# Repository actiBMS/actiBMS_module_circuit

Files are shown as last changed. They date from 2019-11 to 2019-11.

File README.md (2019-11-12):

# diyBMSv5_module_circuit
Version 5 of the diyBMS, this repository contains the pcb project for the cell module

THIS IS A WIP VERSION, SO LAST MINUTE CHANGES COULD BE DONE!

Do it yourself battery management system for Lithium ion battery packs/cells

If you are looking for version 4 of this project take a look here https://github.com/stuartpittaway/diyBMSv4

# How to use, build & support

https://www.youtube.com/stuartpittaway
https://community.openenergymonitor.org/t/diybms-active-balancing/12445/7

# WARNING

This is a DIY product/solution so don’t use this for safety critical systems or in any situation where there could be a risk to life.  

There is no warranty, it may not work as expected or at all.

The use of this project is done so entirely at your own risk.  It may involve electrical voltages which could kill - if in doubt, seek help.

The use of this project may not be compliant with local laws or regulations - if in doubt, seek help.

# License

This work is licensed under a Creative Commons Attribution-NonCommercial-ShareAlike 2.0 UK: England & Wales License.

https://creativecommons.org/licenses/by-nc-sa/2.0/uk/

You are free to:
* Share — copy and redistribute the material in any medium or format
* Adapt — remix, transform, and build upon the material
The licensor cannot revoke these freedoms as long as you follow the license terms.

Under the following terms:
* Attribution — You must give appropriate credit, provide a link to the license, and indicate if changes were made. You may do so in any reasonable manner, but not in any way that suggests the licensor endorses you or your use.
* Non-Commercial — You may not use the material for commercial purposes.
* ShareAlike — If you remix, transform, or build upon the material, you must distribute your contributions under the same license as the original.
* No additional restrictions — You may not apply legal terms or technological measures that legally restrict others from doing anything the license permits.

Notices:
You do not have to comply with the license for elements of the material in the public domain or where your use is permitted by an applicable exception or limitation.

No warranties are given. The license may not give you all of the permissions necessary for your intended use. For example, other rights such as publicity, privacy, or moral rights may limit how you use the material.

# Problem

A DIY Powerwall is the DIY construction of a pack of battery cells to create an energy store which can be used via inverters to power electrical items in the home. Generally cells are salvaged/second hand, and typically use Lithium 18650 cells.

Lithium batteries need to be kept at the same voltage level across a parallel pack. This is done by balancing each cell in the pack to raise or lower its voltage to match the others.

Existing balancing solutions are available in the market place, but at a relatively high cost compared to the cost of the battery bank, so this project is to design a low-cost, simple featured BMS/balancer.

# How it works

Each cell in a battery pack has a monitoring module. Each module have a micro on it that manage all the important task to keep the pack safe. 
This uses AVR ATTINY841 linked together by optoisolated serial ports for communication.

The MCU enable a BYPASS resistor, parallel to the CELL, to dump additional power during charge to keep the pack balanced.
Another solution is to enable the Active Balancing, this feature is based on the ETA3000 chip. It is able to move power between adiacent cells.

A more detailed teory of operation about this inductive converter chip can be read here:
 - https://www.beyondlogic.org/review-li-ion-lipo-lifepo4-lithium-battery-active-equalizer-balancer-energy-transfer-board/
 - https://circuitdigest.com/article/cell-balancing-techniques-and-how-to-use-them

ATTINY841 provides:
* Internal temperature monitoring
* External temperature monitoring
* Autonomous PASSIVE cell voltage balancing
* Autonomous ACTIVE cell voltage balancing

# How as v5 improved over v4?

* Greater discharge current
* Better thermal design for the passive balancing tecnique
* Inductive Active Balancing - Low heat production, less energy loss from your PV

# Design Goals

* Build upon my existing skill set and knowledge. 
* Building something that others can contribute to using regular standard libraries and off the shelf components.
* Build something that is inheriently safe and easy to use
* Document it to inspire other people

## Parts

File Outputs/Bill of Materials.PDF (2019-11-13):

Comment | Description | Designator | Quantity | Supplier | SuppliersPartNum ber | Manufacturer | PartNumber
100nF | Chip capacitors | C1 | 1 | LC | C49678 | YAGEO | CC0805KRX7R9BB 104
2.2uF | Chip capacitors | C2 | 1 | LC | C49217 | Guangdong Fenghua Advanced Tech | 0805F225M500NT
10uF | Chip capacitors | C3, C6, C7 | 3 | LC | C15850 | Samsung Electro-Mechanics | CL21A106KAYNN NE
1nF | Chip capacitors | C4 | 1 | LC | C46653 | Samsung Electro-Mechanics | CL21B102KBCNN NC
10nF | Chip capacitors | C5 | 1 | LC | C1710 | Samsung Electro-Mechanics | CL21B103KBANN NC
LM4040B-2.0 | Precision Shunt Voltage Reference | D1 | 1
0805 Blue | LED | D2 | 1 | LC | C2293
0805 Red | LED | D3 | 1 | LC | C84256 | Foshan NationStar Optoelectronics | FC-2012HRK-620D
JST PH 4POS 2.00mm | JST-PH Conn | J1 | 1 | LC | C157926 | JST Sales America | S4B-PH-K-S(LF)(SN)
JST PH 2POS 2.00mm | JST-PH Conn | J2, J5 | 2 | LC | C173752 | JST Sales America | S2B-PH-K-S(LF)(SN)
JST PH 3POS 2.00mm | JST-PH Conn | J3 | 1 | LC | C157929 | JST Sales America | S3B-PH-K-S(LF)(SN)
AVR-ISP-6 | | J6 | 1 | LC | C65114 | Boom Precision Elec | C65114
SM3521-1R0MT | Power Inductor | L1 | 1 | LC | C55366 | Shun Xiang Nuo Elec | SM3521-1R0MT
WS2812B-Mini | RGB Addressable LED | LED1 | 1 | LC | C114583 | Worldsemi | WS2812B-Mini
2Ω ±1% | Chip resistor | PR1, PR2, PR3, PR4, PR5, PR6, PR7, PR8, PR9, PR10, PR11, PR12 | 12 | LC | C49298 | Uniroyal Elec | 25121WF200KT4 E
IRLML6244TRPBF | MOSFET-N | Q1, Q2 | 2 | LC | C143946 | Infineon Technologies | IRLML6244TRPBF
10KΩ ±1% | Chip resistor | R1 | 1 | LC | C17414 | Uniroyal Elec | 0805W8F1002T5E
1KΩ ±1% | Chip resistor | R2 | 1 | LC | C17513 | Uniroyal Elec | 0805W8F1001T5E
402KΩ ±1% | Chip resistor | R3 | 1 | LC | C17680 | Uniroyal Elec | 0805W8F4023T5E
510KΩ ±1% | Chip resistor | R4 | 1 | LC | C17733 | Uniroyal Elec | 0805W8F4023T5E
NCP21WB473J03RA | NTC Resistor 47K 5% | R5 | 1 | LC | C113141 | Murata Electronics | NCP21WB473J03 RA
47KΩ ±1% | Chip resistor | R6, R7, R9, R12, R16 | 5 | LC | C17713 | Uniroyal Elec | 0805W8F4702T5E
510Ω ±1% | Chip resistor | R8, R11 | 2 | LC | C17734 | Uniroyal Elec | 0805W8F5100T5E
2.2KΩ ±1% | Chip resistor | R10, R15 | 2 | LC | C17520 | Uniroyal Elec | 0805W8F2201T5E
51KΩ ±1% | Chip resistor | R17 | 1 | LC | C17737 | Uniroyal Elec | 0805W8F5102T5E
ATTINY841-SSU | AtTiny AVR | U1 | 1 | LC | C219103 | Microchip Tech | ATTINY841-SSU
HMHA2801 | Optocoupler | U2 | 1 | LC | C258257 | ON Semicon | HMHA2801AR2
ETA3000D2L | Inductive Cell Balancer IC | U3 | 1 | | | ETA Solutions | ETA3000D2L

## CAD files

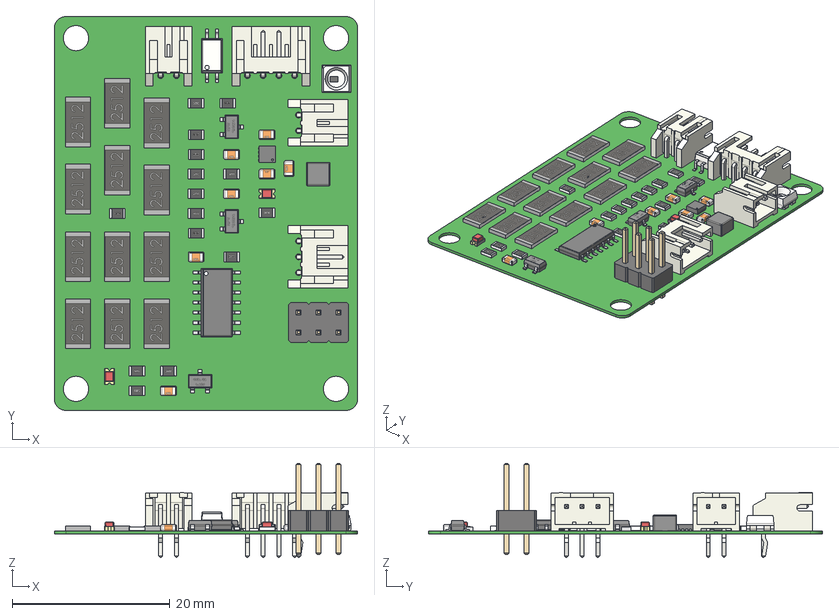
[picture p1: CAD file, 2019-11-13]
Outputs/board.step
38.5 x 50.0 x 11.9 mm
PinHeader_2x03_P2.54mm_Vertical
JST_PH_S2B-PH-K_1x02_P2.00mm_Horizontal x 2
JST_PH_S3B-PH-K_1x03_P2.00mm_Horizontal
JST_PH_S4B-PH-K_1x04_P2.00mm_Horizontal
Open_CASCADE_STEP_translator_6.8_19.1
Open_CASCADE_STEP_translator_6.8_19.2.1
Thermal_Shape
Open_CASCADE_STEP_translator_6.8_19.4.1 x 8
WS2812B_Mini
L_Wuerth_MAPI-3020
Open_CASCADE_STEP_translator_6.8_24.2
Leader x 18
Open_CASCADE_STEP_translator_6.8_8.1
Open_CASCADE_STEP_translator_6.8_8.2.1
User_Library-R_0805 x 15
SOT-23 x 3
User_Library-res2512_body x 12
User_Library-led_0805 x 2
User_Library-0805_SMD_Capacitor x 7

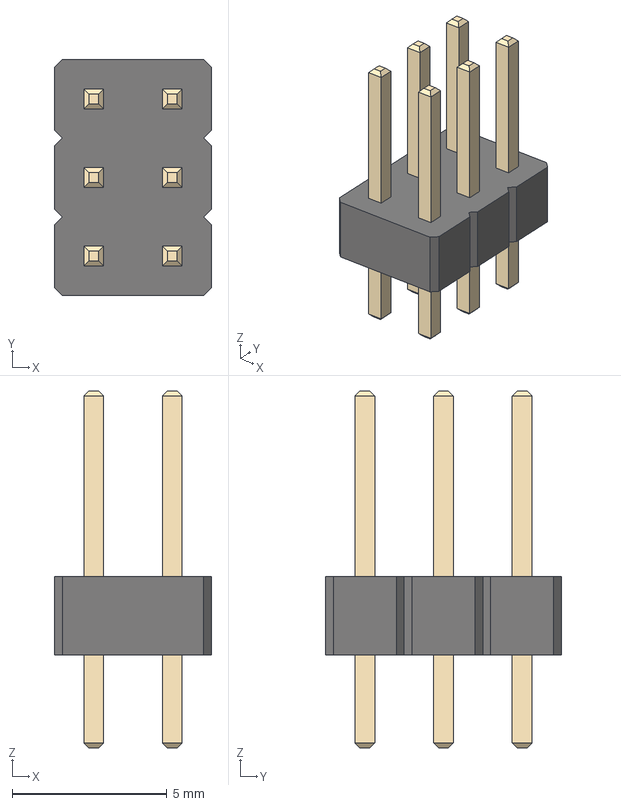
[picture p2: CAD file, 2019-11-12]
PinHeader_2x03_P2.54mm_Vertical.step
5.08 x 7.62 x 11.5 mm

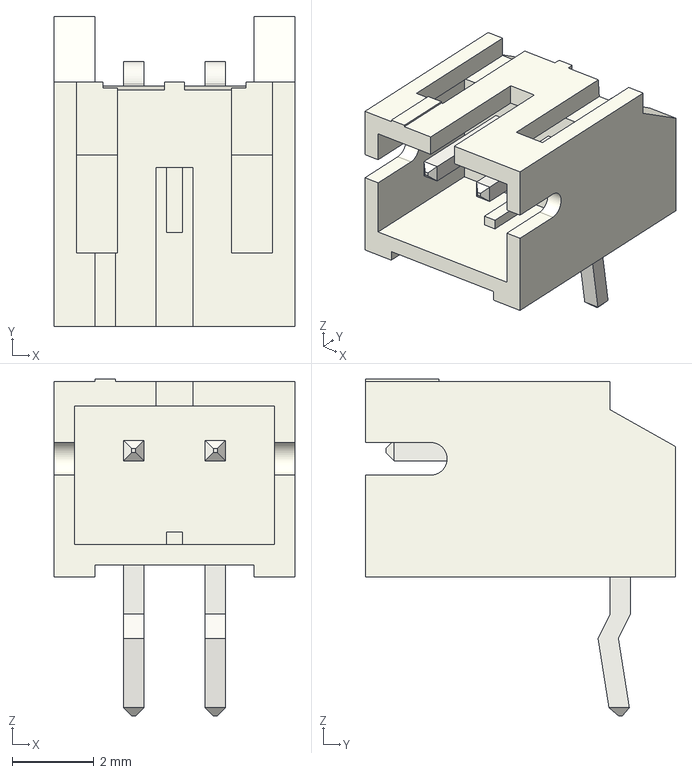
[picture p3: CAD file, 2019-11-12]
JST_PH_S2B-PH-K_1x02_P2.00mm_Horizontal.step
5.90 x 7.60 x 8.25 mm

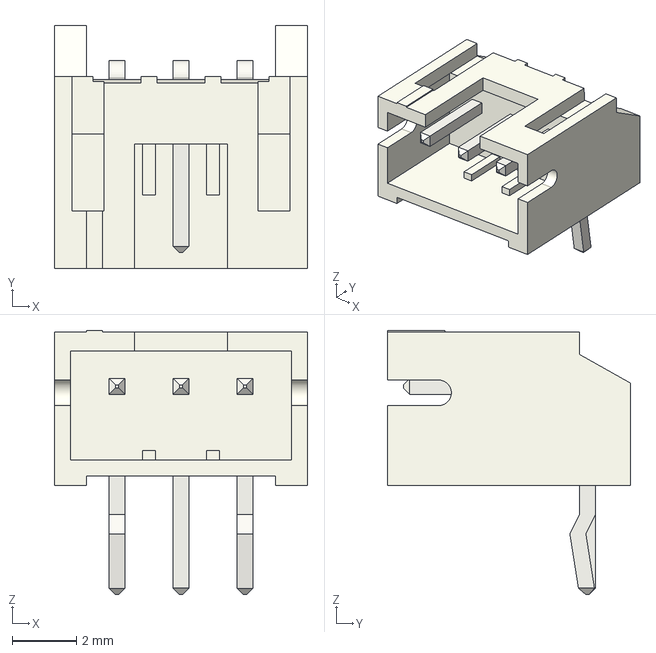
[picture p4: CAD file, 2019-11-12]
JST_PH_S3B-PH-K_1x03_P2.00mm_Horizontal.step
7.90 x 7.60 x 8.25 mm

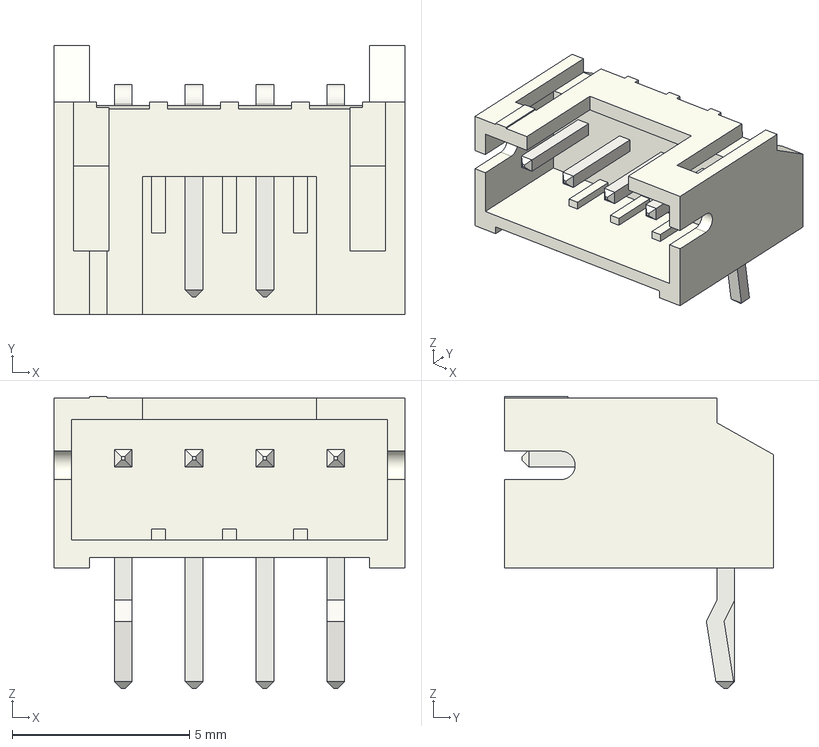
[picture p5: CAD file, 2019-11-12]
JST_PH_S4B-PH-K_1x04_P2.00mm_Horizontal.step
9.90 x 7.60 x 8.25 mm

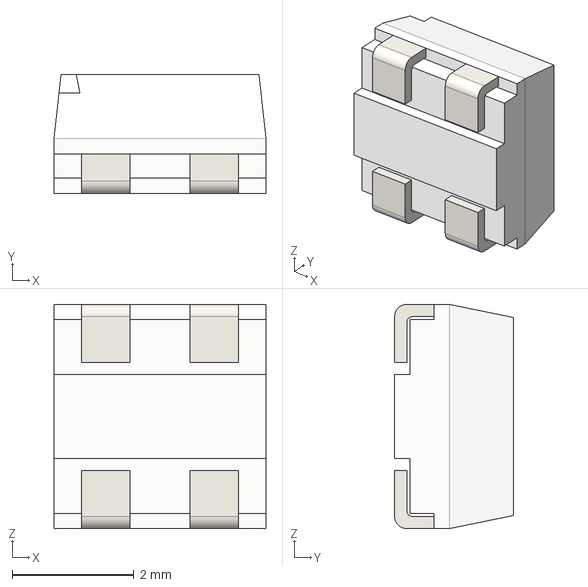
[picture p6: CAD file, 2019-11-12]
WS2812B Mini.step
3.48 x 1.95 x 3.68 mm

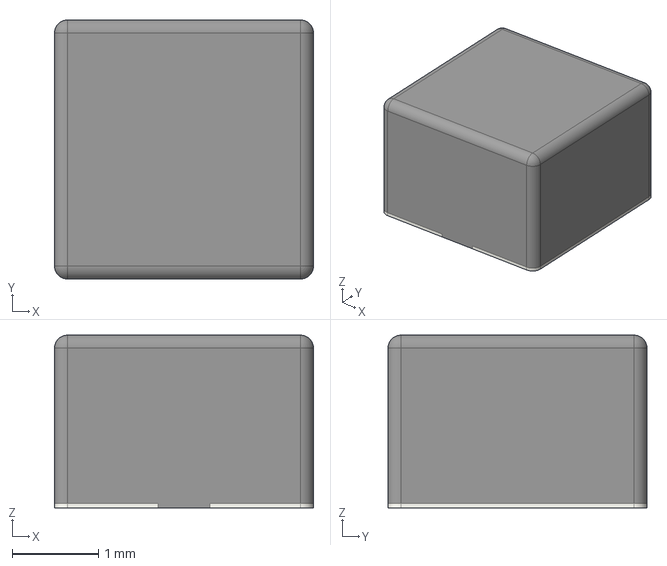
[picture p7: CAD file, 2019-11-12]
L_Wuerth_MAPI-3020.step
3.00 x 3.00 x 2.00 mm

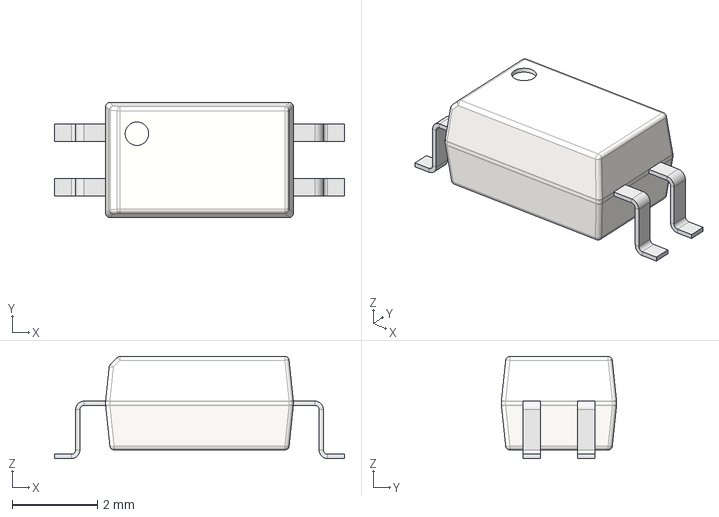
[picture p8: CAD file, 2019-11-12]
HMHA2801 v2.step
6.79 x 2.70 x 2.39 mm
Open_CASCADE_STEP_translator_6.8_24.2
Leader x 4

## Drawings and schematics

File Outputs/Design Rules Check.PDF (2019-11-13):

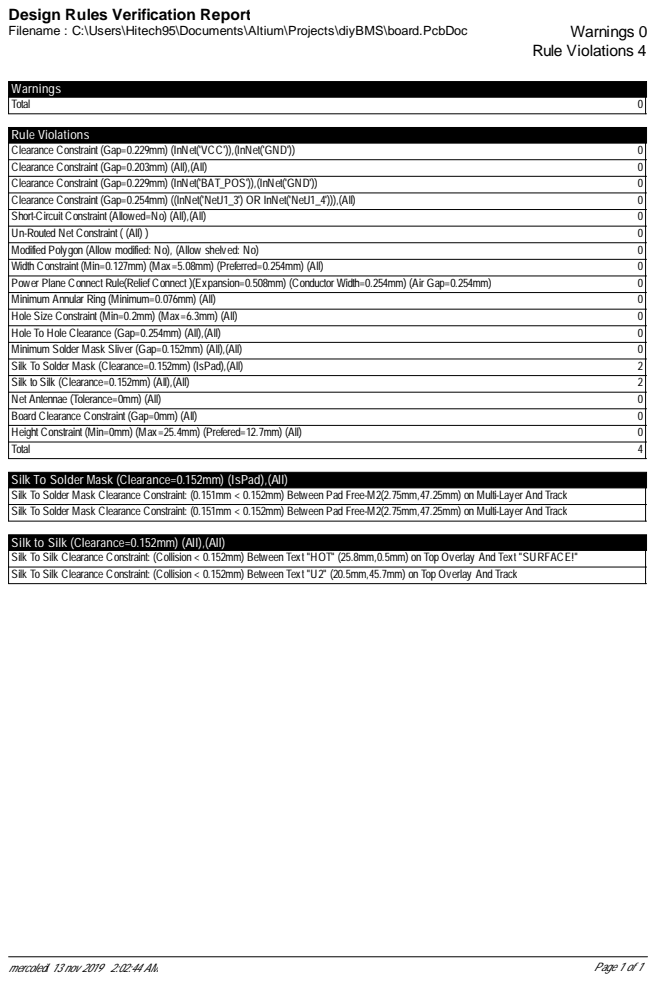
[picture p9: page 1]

Design Rules Verification Report

Silk To Solder Mask (Clearance=0.152mm) (IsPad),(All)
Silk To Solder Mask Clearance Constraint: (0.151mm < 0.152mm) Between Pad Free-M2(2.75mm,47.25mm) on Multi-Layer And Track

Silk to Silk (Clearance=0.152mm) (All),(All)
Silk To Silk Clearance Constraint: (Collision < 0.152mm) Between Text "HOT" (25.8mm,0.5mm) on Top Overlay And Text "SURFACE!"
Silk To Silk Clearance Constraint: (Collision < 0.152mm) Between Text "U2" (20.5mm,45.7mm) on Top Overlay And Track

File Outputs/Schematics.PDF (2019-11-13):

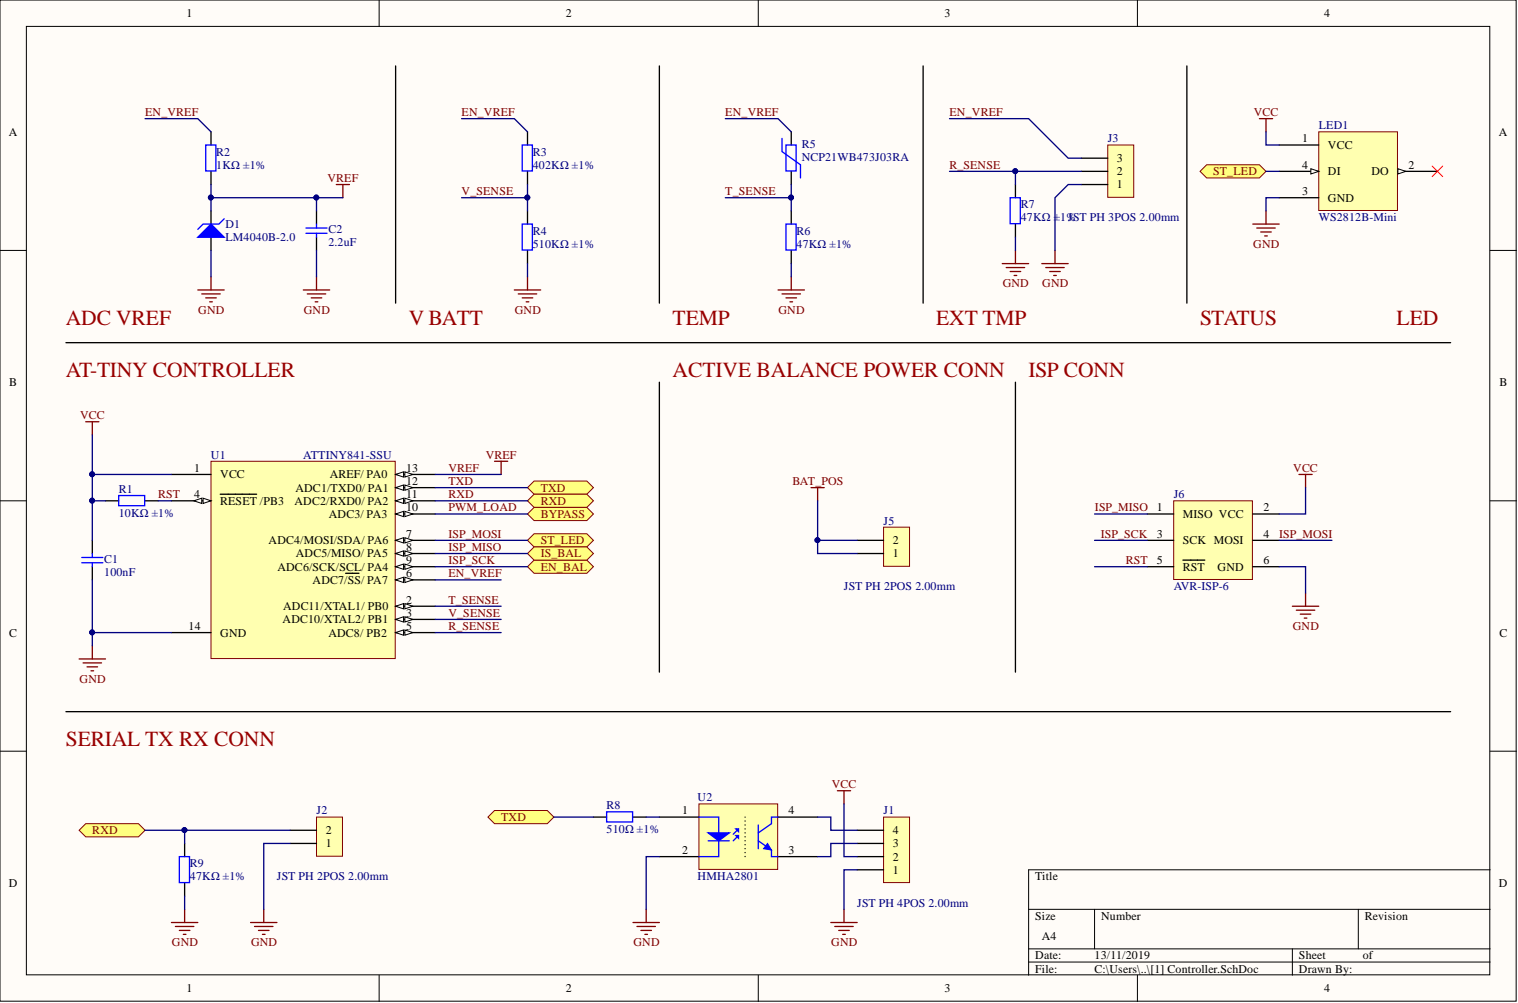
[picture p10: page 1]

ACTIVE BALANCE POWER CONN

SERIAL TX RX CONN

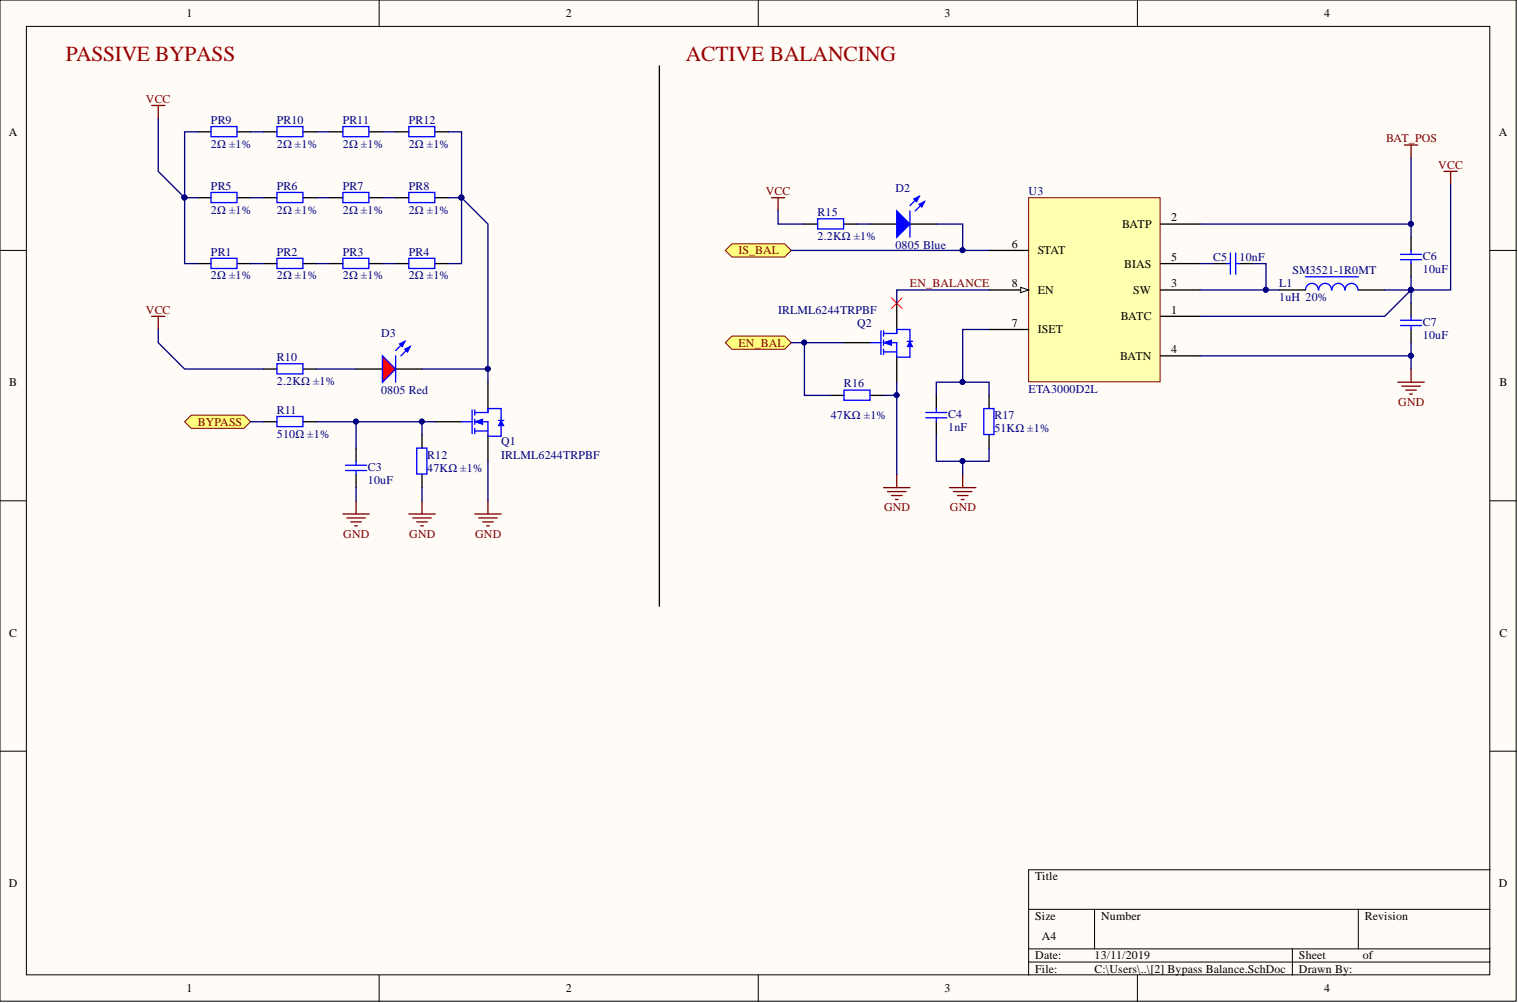
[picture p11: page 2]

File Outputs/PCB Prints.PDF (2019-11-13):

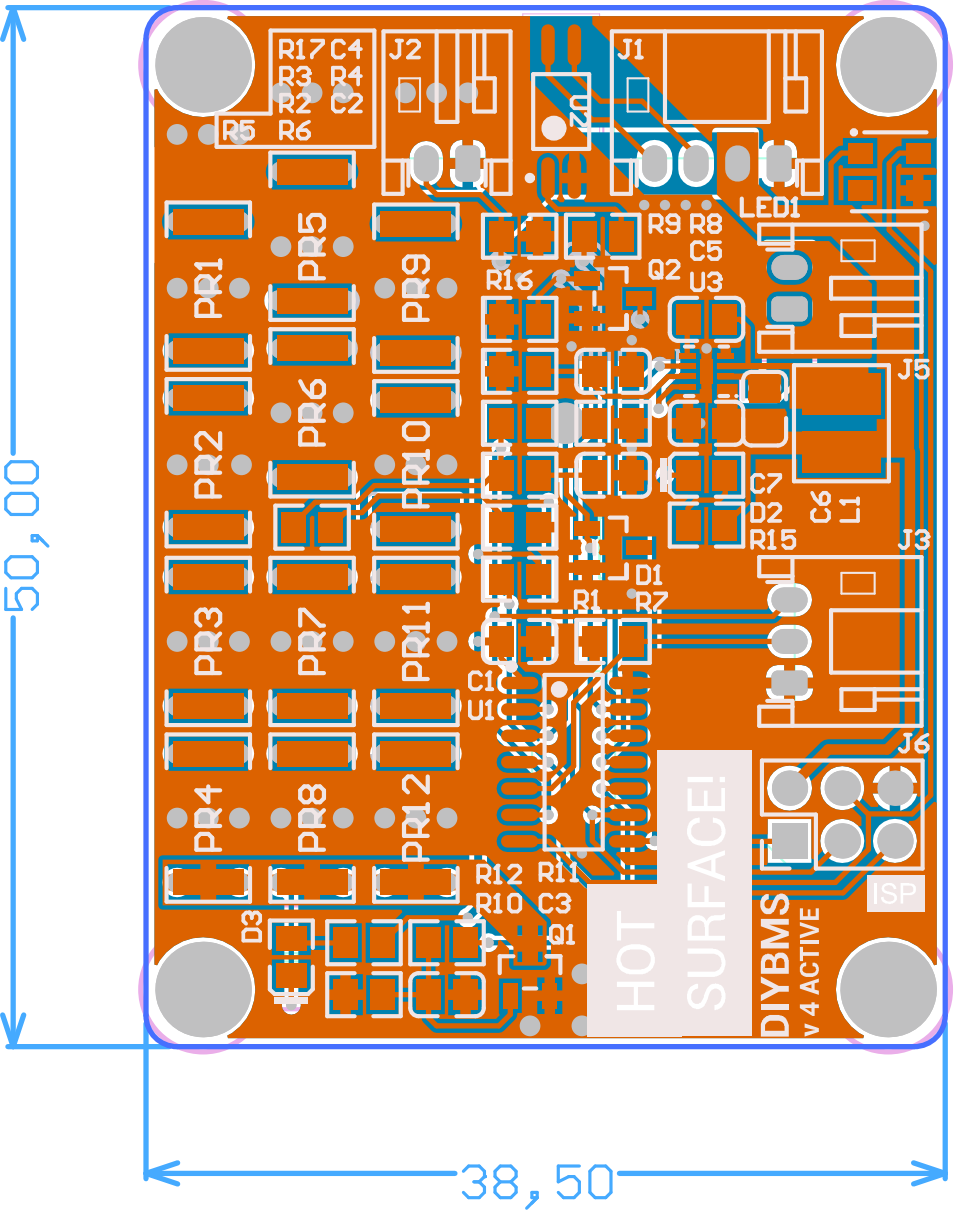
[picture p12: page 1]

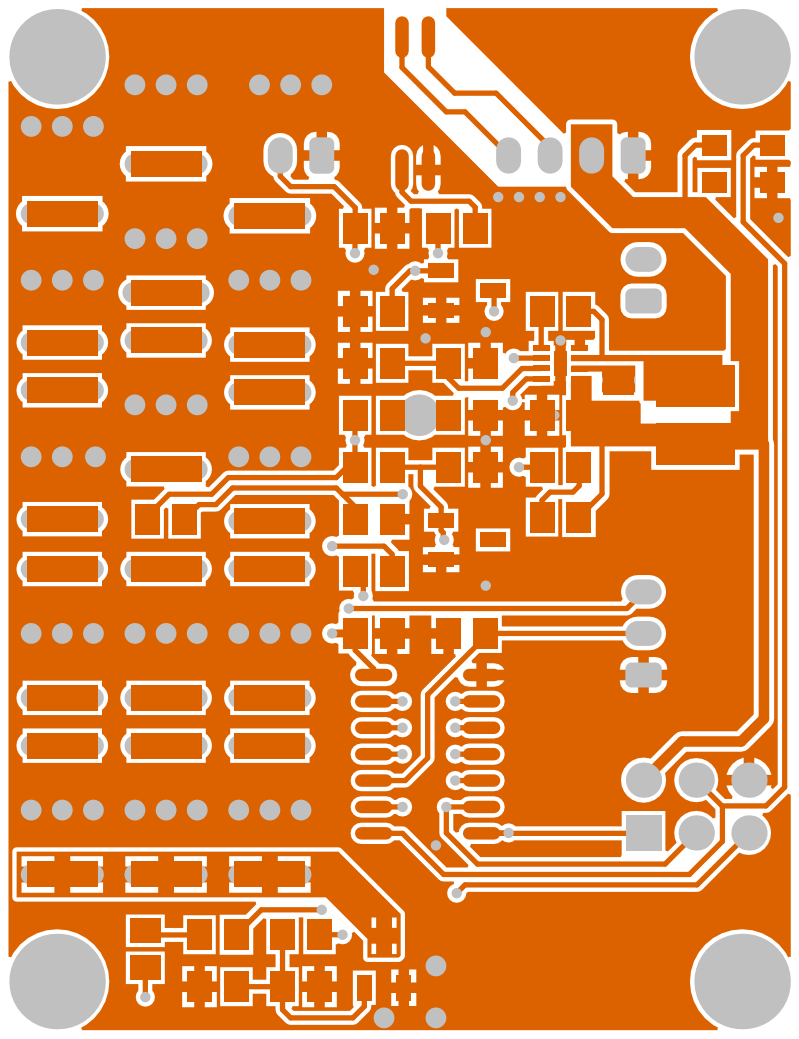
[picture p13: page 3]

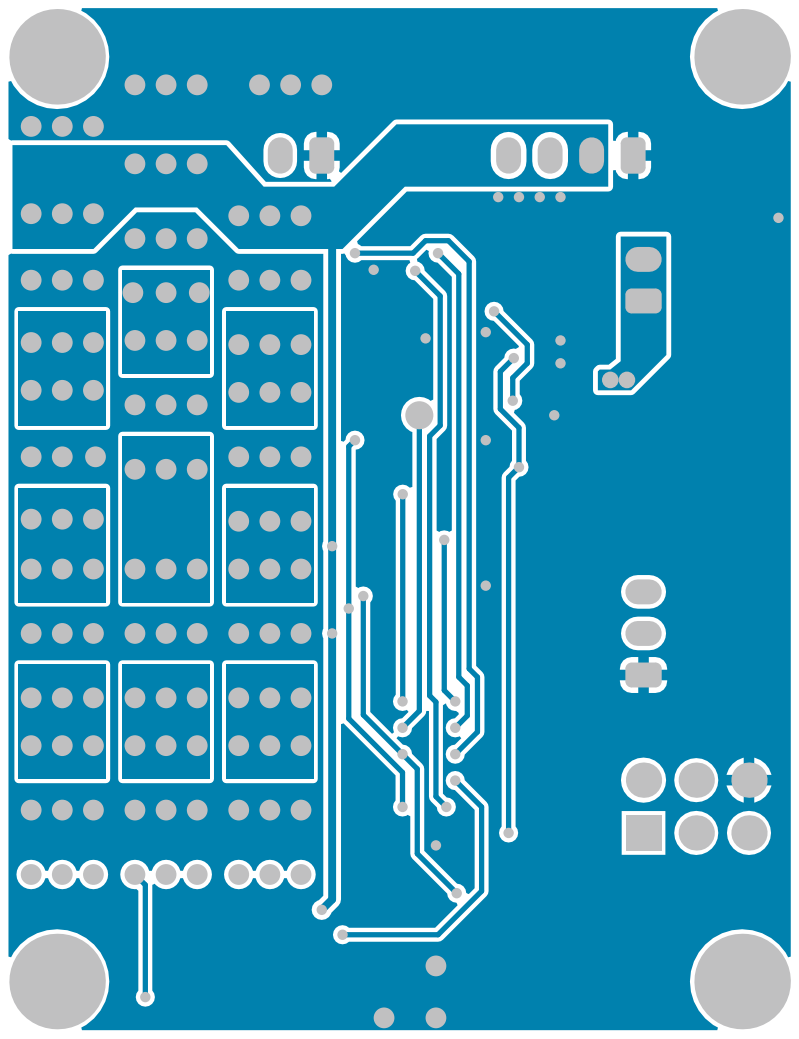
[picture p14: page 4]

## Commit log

2019-11-12 [3D] Upload the 3D Models used by the footprints
    [HMHA2801 v2.step, JST_PH_S2B-PH-K_1x02_P2.00mm_Horizontal.step, JST_PH_S3B-PH-K_1x03_P2.00mm_Horizontal.step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]
2019-11-12 Commit of SCH and PCB
    [BMS_PcbLib.PcbLib, BMS_SchLib.SchLib, [1] Controller.SchDoc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]
2019-11-12 Add Oputput files
    Some of thoose are still not usable, the export process has not been completly configured!
    [Bill of Materials-diyBMS.xlsx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]
2019-11-13 Fixed a libraries, updated project files
    [BMS_PcbLib.PcbLib, [1] Controller.SchDoc, [2] Bypass Balance.SchDoc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]
2019-11-13 Update Outputs
    [Bill of Materials-diyBMS.xlsx, Pick Place for board.csv, board.step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]
2019-11-15 Move from ATtiny to ATmega to have more SRAM, Flash and its cheaper! ATmega168p can also be assembled by SMT process at JLCPCB
    [BMS_PcbLib.PcbLib, BMS_SchLib.SchLib, [1] Controller.SchDoc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]

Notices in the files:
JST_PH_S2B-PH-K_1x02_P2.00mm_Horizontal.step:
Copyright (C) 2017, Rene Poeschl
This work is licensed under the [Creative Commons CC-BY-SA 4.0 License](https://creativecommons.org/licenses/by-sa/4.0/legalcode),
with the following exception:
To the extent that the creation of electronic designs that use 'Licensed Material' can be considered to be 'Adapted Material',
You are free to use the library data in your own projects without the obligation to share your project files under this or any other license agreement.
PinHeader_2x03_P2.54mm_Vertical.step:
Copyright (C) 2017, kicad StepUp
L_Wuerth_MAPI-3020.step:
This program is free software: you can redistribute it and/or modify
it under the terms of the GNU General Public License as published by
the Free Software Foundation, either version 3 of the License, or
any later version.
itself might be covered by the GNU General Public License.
